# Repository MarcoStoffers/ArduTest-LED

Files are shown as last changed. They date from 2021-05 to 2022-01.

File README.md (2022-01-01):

# ArduTest-LED
ledtest_front

Based on an idea of https://jaycar.com.au

## Update: new Firmware V0.6 with adjustable LED PWM start voltage

The PWM start voltage for testing the LED was fixed set to 2.5V. This was good for standard LEDs. But if you want to test white or blue LEDs with 3V or higher, it won't work. So I added a setup for this startup voltage. Press "I up" ("Strom +") while switching on the tester and wait for the startup screen to complete.

lcdvstartsetup

Now you can adjust the LED voltage with the "V up" ("Spannung +") and "V down" ("Spannung -") keys. IF YOU SET THIS VOLTAGE TO HIGH, YOUR LED WILL BLOW UP! For storing this value, press "I down" ("Strom -") key.

If this is the first power up for new firmware version, the default value of 2.5V will be stored in EEprom. You will see a short notice on the LCD

eeprominitok

## An Arduino based LED Tester with LCD

Select the current and the destination voltage (your battery), connect the LED to the tester and get the needed value for a serial connected Resistor. You can also see the measured values for the LED (forward voltage and current).

To dimm the LED, you can lower the current during measurement down to 3mA or up to 40mA. The Tester always starts with a default current of 10mA!

## Tips for DIYing

The housing is designed in Fusion360. You can print it on any 3D FDM Printer with PLA or any other material you want. You will need 4x threaded inserts in M3 and 4 screws M3x25 to hold the front on the housing. The Frontplate is desgined in Inkscape in german. You can edit the SVG file for your own like.

The buttons are also designed in Fusion360. You will need an SLA Printer to get good results (FDM Printer will not work here fine).

## EasyEDA Source for PCB ordering through JLCPCB

https://oshwlab.com/mstoffers/ArduTest-LED

## License

CreativeCommonLicense

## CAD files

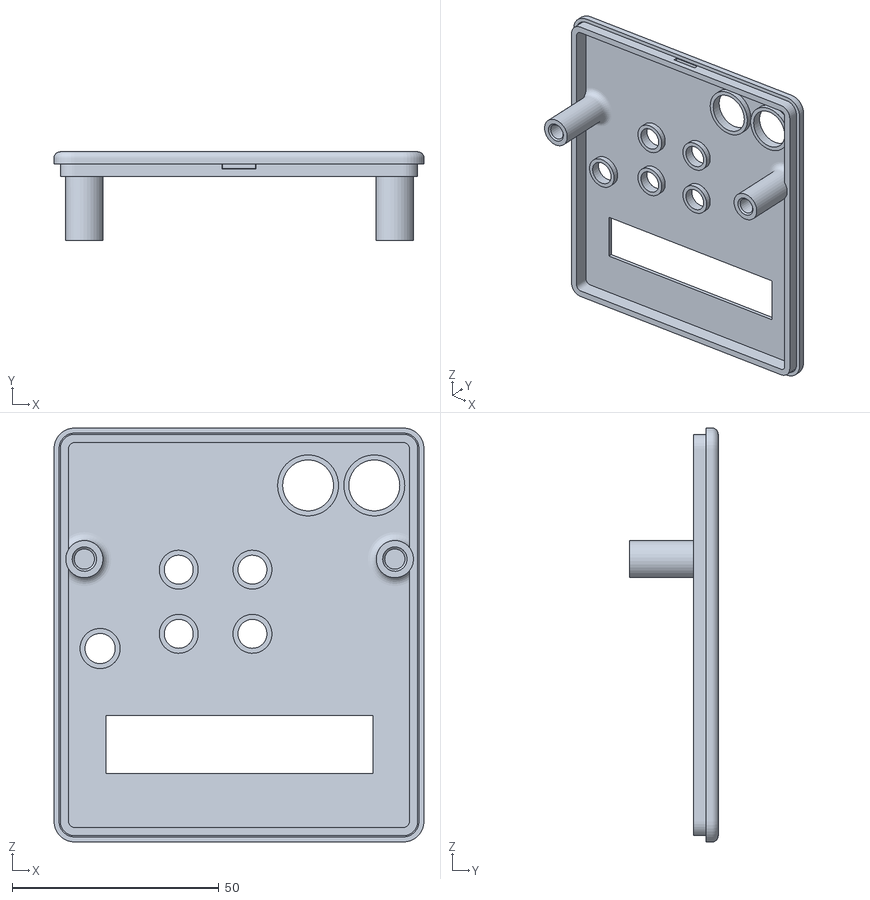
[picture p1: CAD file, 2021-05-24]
Housing/ArduTest LED Housing Top.stl
89.4 x 21.4 x 100.0

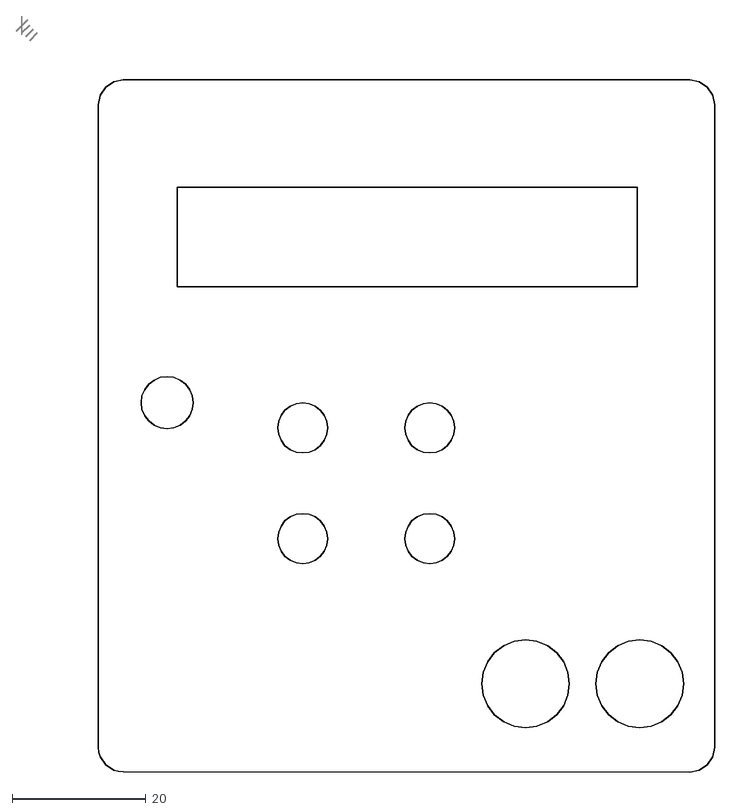
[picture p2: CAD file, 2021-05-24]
Housing/ArduTest LED Housing Front.dxf
104.4 x 113.0

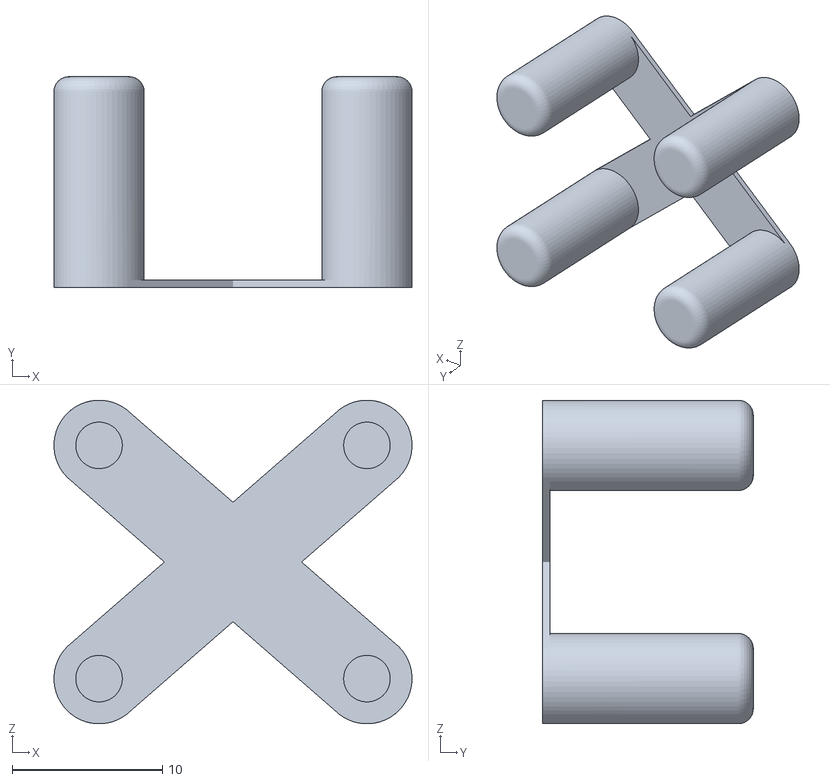
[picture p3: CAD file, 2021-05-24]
Housing/ArduTest LED Housing Button 4x.stl
23.8 x 14.0 x 21.5

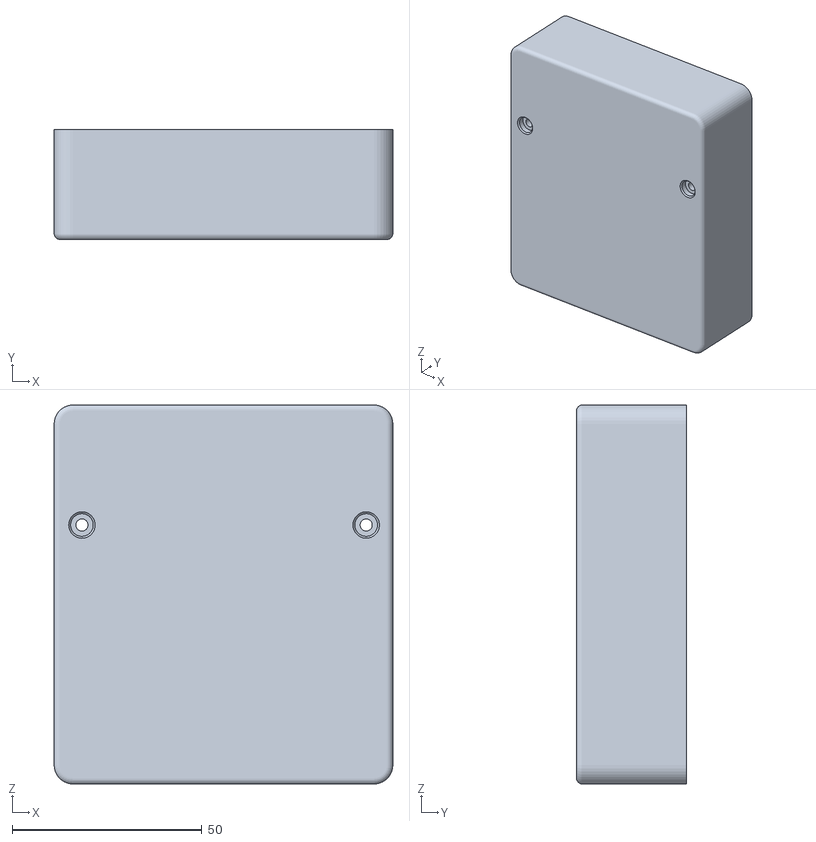
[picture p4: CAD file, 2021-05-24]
Housing/ArduTest LED Housing Bottom.stl
89.4 x 29.0 x 100.0

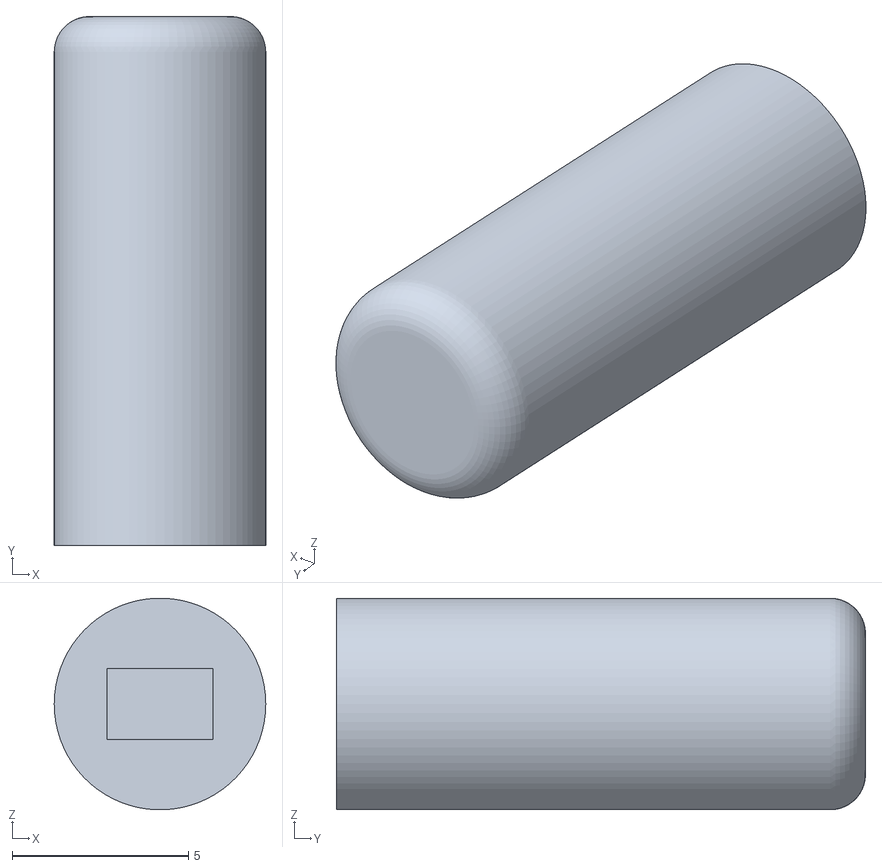
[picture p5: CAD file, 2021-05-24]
Housing/ArduTest LED Housing Button Power.stl
6.00 x 15.0 x 5.99

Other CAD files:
Housing/ArduTest LED Housing.f3z

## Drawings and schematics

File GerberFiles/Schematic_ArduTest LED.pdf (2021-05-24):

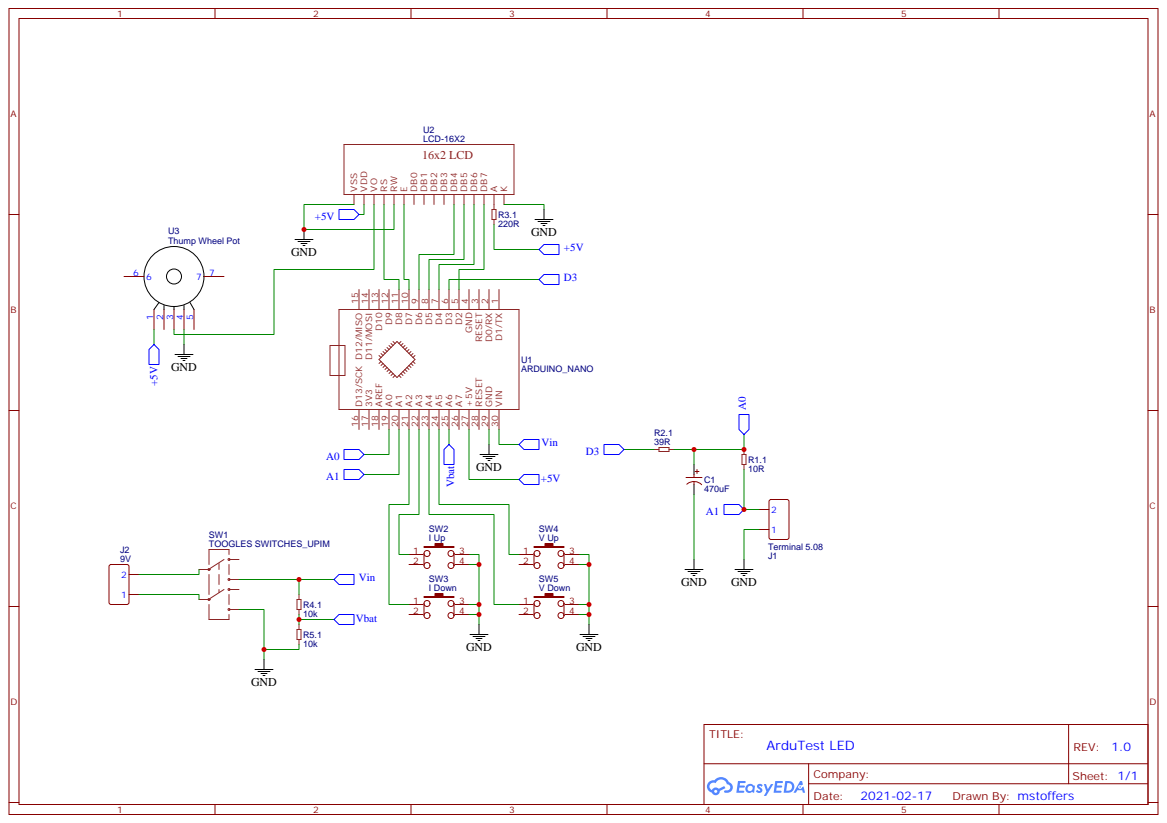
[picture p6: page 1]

1 VIN 30 GND 29 RESET 28 +5V 27 A7 26 A6 25 A5 24 A4 23 A3 22 A2 21 A1 20 A0 19 AREF 18 3V3 17 D13/SCK 16 D12/MISO 15

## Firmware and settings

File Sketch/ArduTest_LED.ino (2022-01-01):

/* -----------------------------------------------------------------------
**  ArduTest LED
** ==============
**
**  Original from https://jaycar.com.au
**
**  DPIN--39R--+--10R---TESTLED---GND
**         |      |         |
**        470u    ATOP     ABOT
**         |
**        GND
**
**  Measures LED characteristics by charging up the cap to deliver target 
**  current and find forward voltage. From target current, we can calculate 
**  R to be used with a design supply voltage.
**  
**  Revision History:
**  0.1: - take original code and port it no new Hardware
**  0.2: - optimize code and cleanup
**  0.3: - rewrite LCD display routine to minimize flicker
**  0.4: - rewrite PWM routine to avoid LED over current
**  0.5: - add voltage test routine while pressing I-Down at startup
**  0.6: - add setup for led forward voltage at measure-start (be careful what you are doing here!)
**
** Inputs:
** --------
** A0 = analog Voltage ATOP
** A1 = analog Voltage ABOT
** A2 = Key I Down
** A3 = Key I Up
** A4 = Key V Down
** A5 = Key V Up
** A6 = analog Voltage Battery
**
** Outputs:
** ---------
** D8 = LCD RS 
** D7 = LCD Enable
** D6 = LCD Data 4
** D5 = LCD Data 5
** D4 = LCD Data 6
** D2 = LCD Data 7
** D3 = PWM output
** 
** EEPROM data:
** -------------
** 0 - values stored? (255 = no / 0 = yes)
** 1 - LED voltage start PWM vlaue (8bit)
**
** Board:
** -------
** Arduino Nano V3 | Print: ArduTest LED V0.2
** 
** Author: M.Stoffers
** Year: 2022
** License: CC (BY|NC|SA)
** -------------------------------------------------------------------------*/  
#include <LiquidCrystal.h>
#include <avr/eeprom.h>

// -----------------------------
// PIN-defines
// -----------------------------
#define Version "V0.6"
#define LCD_D2 2
#define LCD_D4 4
#define LCD_D5 5
#define LCD_D6 6
#define LCD_D7 7
#define LCD_D8 8
#define DPIN 3
#define ATOP A0
#define ABOT A1
#define ABAT A6
#define KEY_I_UP A3
#define KEY_I_DW A2
#define KEY_V_UP A5
#define KEY_V_DW A4

// -----------------------------
// System-defines
// -----------------------------
#define OSAMP 16                                                  // Number of oversamples
#define LCDINT 250                                                // LCD update interval
#define KEYINT 150                                                // Key check interval
#define VCCINT 5000                                               // VCC read interval

#define between(x, a, b)  (((a) <= (x)) && ((x) <= (b)))

// -----------------------------
// declares
// -----------------------------
LiquidCrystal lcd(LCD_D8, LCD_D7, LCD_D6, LCD_D5, LCD_D4, LCD_D2);

// -----------------------------
// variables
// -----------------------------
uint8_t pins[]={KEY_I_UP, KEY_I_DW, KEY_V_UP, KEY_V_DW};          // array of Key pins

uint8_t ma_Char[] = { 0x0A, 0x15, 0x15, 0x00, 0x0E, 0x11, 0x1F, 0x11 };
uint8_t set1_Char[] = { 0x09, 0x15, 0x11, 0x09, 0x05, 0x15, 0x09, 0x00 };
uint8_t set2_Char[] = { 0x17, 0x02, 0x02, 0x12, 0x02, 0x02, 0x12, 0x00 };
uint8_t led1_Char[] = { 0x00, 0x0C, 0x0A, 0x09, 0x18, 0x09, 0x0A, 0x0C };
uint8_t led2_Char[] = { 0x03, 0x13, 0x14, 0x10, 0x1F, 0x10, 0x10, 0x10 };
uint8_t bat1_Char[] = { 0x00, 0x0C, 0x1E, 0x1E, 0x1E, 0x1E, 0x1E, 0x1E };
uint8_t bat2_Char[] = { 0x00, 0x0C, 0x1E, 0x12, 0x12, 0x1E, 0x1E, 0x1E };
uint8_t bat3_Char[] = { 0x00, 0x0C, 0x1E, 0x12, 0x12, 0x12, 0x12, 0x1E };

uint16_t VCC;                                                     // exact VCC
uint32_t vbat;                                                    // battery voltage
uint8_t pwmout=0;                                                 // pwm output of current driver
long atop, abot, arr, abat;                                       // analog sample values
long vled, vrr, irr, pset;                                        // LED voltage, Resistor voltage, resistor current, display power
uint8_t itest=10;                                                 // test current, starting at 10mA
uint32_t vset =12000;                                             // display voltage, start at 12V
uint8_t battery_status;                                           // battery status to display bat symbol

uint32_t r_calc, rval, r24[]={10,11,12,13,15,16,18,20,22,24,27,30,33,36,39,43,47,51,56,62,68,75,82,91};
uint16_t r24_mul;                                                 // variables to determine R24 value
uint8_t r24_loop;
boolean r24_found;
boolean rvalid=false;                                             // flag if resistor value is valid 

boolean lcdflash = false;                                         // lcd flashing phase variable
long lastlcd=0, lastkey=0, lastvcc=0;                             // time of last lcd & key update

uint16_t LED_forw_v_start;                                        // LED measure startup up voltage
uint16_t vsetup=0;
boolean while_loop = true;

// -----------------------------
// Setup
// -----------------------------
void setup() {
  pinMode(DPIN,OUTPUT);                                           // Set PWM pin aus Output
  for(uint8_t i=0; i<4; i++) pinMode(pins[i], INPUT_PULLUP);      // Define button Pins as Input with Pullup resistors

  readVcc();                                                      // Read VCC ...

  analogReference(DEFAULT);                                       // ... set ADC Reference back to default
  delay(2);                                                       // ... and wait for ADC to become stable
  
  lcd.begin(16, 2);                                               // LCD initialize 
  
  lcd.createChar(1, ma_Char);                                     // create special character#1 : mA
  lcd.createChar(2, set1_Char);                                   // create special character#2 : SE
  lcd.createChar(3, set2_Char);                                   // create special character#3 : T
  lcd.createChar(4, led1_Char);                                   // create special character#4 : LED symbol left
  lcd.createChar(5, led2_Char);                                   // create special character#5 : LED symbol right
  lcd.createChar(6, bat1_Char);                                   // create special character#6 : Battery symbol full
  lcd.createChar(7, bat2_Char);                                   // create special character#6 : Battery symbol half
  lcd.createChar(8, bat3_Char);                                   // create special character#6 : Battery symbol empty

  abat = analogoversample(ABAT,OSAMP);                            // read battery voltage and calc to mV
  vbat = (abat * VCC/1023)*2;

  if(between(vbat,8700,9900)) battery_status = 1;                 // decide to show which battery symbol
  else if(between(vbat,8000,8699)) battery_status = 2;            // 1=full, 2=half, 3=empty
  else battery_status = 3;                                        // if voltage to low, show empty battery symbol

  Check_EEPROM();                                                 // check if EEPROM is already initialized and read values
  
  StartupScreen();                                                // Show Startup Screen

  if(!digitalRead(KEY_I_DW)) Voltage_Test();                      // If key "current down" is pressed at startup, call Sub voltage test
  if(!digitalRead(KEY_I_UP)) Voltage_Setup();                     // If key "current up" is pressed at startup, call Sub voltage setup
  
  Draw_Init_LCD();
}

// -----------------------------
// Mainprogram
// -----------------------------
void loop() {
  rvalid=false;                                                   // set flag to not valid
  pset=0;                                                         // set power consumption var to zero
  
  atop = analogoversample(ATOP,OSAMP);                            // read voltage ATOP
  abot = analogoversample(ABOT,OSAMP);                            // and ABOT including oversample
  
  arr = atop - abot;                                              // this is the analog value across the 10R sense resistor
  if(arr < 0) arr = 0;                                            // sanity check
  
  vled = abot * VCC/1023;                                         // calc voltage across LED
  vrr = arr * VCC/1023;                                           // calc voltage across sense resistor
  irr = vrr / 10;                                                 // led and resistor current in mA

  if(irr < 1) pwmout = LED_forw_v_start;                          // if test LED is not present put PWM to given startup voltage 
  else {
    if(irr < itest) {                                             // ramp up current if too low
      pwmout++;
      if(pwmout > 255) pwmout = 255;
    }    
    if(irr > itest){                                              // ramp down if too high
      pwmout--;
      if(pwmout < 0) pwmout = 0;
    }
    if(irr > 34){                                                 // ramp down quick if too too high
      pwmout = pwmout - 5;
      if(pwmout < 0) pwmout = 0;
    }
    if(irr > itest * 3){                                          // ramp down quick if too too high
      pwmout = pwmout - 5;
      if(pwmout < 0) pwmout = 0;
    }
  }
  analogWrite(DPIN,pwmout);                                       // output new PWM

  if(irr < 1) rvalid = false;
  else if(vled > vset) rvalid = false;                            //if vled>vset, no valid resistor exists
  else {
    r_calc = (vset - vled) / itest;                               // calc needed resistor

    r24_mul = 1;                                                  // set all var for R24 search to start
    r24_loop = 0;
    r24_found = false;
  
    while(r24_loop < 4) {                                         // find next highest E24 value
      for(int i=0;i<24;i++){                                      
        if(!r24_found && ((r24[i] * r24_mul) > r_calc)){
          rval = r24[i]*r24_mul;
          rvalid=true;
          r24_found=true;
          r24_loop = 4;
       }
      }
      if(!rvalid) {                                               // if R24 search before has not matched
       r24_loop ++;                                                
       r24_mul *= 10;                                             // try next decade
      }
    }
  }
  if(abs(irr-itest)>(itest/5)+1){rvalid=false;}                   // has current settled within 20%?
  
  if(rvalid){pset=itest*itest*rval;}                              // this will be in microwatts (milliamps squared)
  
  if(millis()-lastlcd>LCDINT){                                    // check if display needs to be updated
    lastlcd=millis();
    dolcd();                                                      // update display
    lcdflash=!lcdflash;                                           // toggle flash variable
  }
  if(millis()-lastkey>KEYINT){                                    // do keys needs to be checked?
    lastkey=millis();
    dobuttons();
  }
  if(millis()-lastvcc>VCCINT){                                    // do VCC needs to be re-read?
    lastvcc=millis();
    readVcc();                                                    // Read VCC ...

    analogReference(DEFAULT);                                     // ... set ADC Reference back to default  
    delay(2);                                                     // ... and wait for ADC to become stable
  }
  delay(1);
} 

// -----------------------------
// Subroutine to update LCD
// -----------------------------
void dolcd(){
  lcd.setCursor(3,0);                                             // set postion first line|4th character
  if(itest>9) lcd.write(((itest/10)%10)+'0');                     // write tens of I-Test ...
  else lcd.write(' ');                                            // ... blank tens if zero
  lcd.write((itest%10)+'0');                                      // write ones of I-Test
  lcd.write(1);                                                   // write mA symbol and spacer
  lcd.write('|');
  
  if(vset>9999) lcd.write(((vset/10000)%10)+'0');                 // write tens of V-Set ..
  else lcd.write(' ');                                            // ... blank if zero
  lcd.write(((vset/1000)%10)+'0');                                // write ones of V-Set
  lcd.write('v');lcd.write(' ');                                  // and the electrical characteristic
  
  
  if((pset>249999)&&(lcdflash)){                                  // if power is above 1/4 watt
    lcd.setCursor(15,1);                                          // blink a 'P' on position 16 in line 2
    lcd.write('P');
  }
  else {
    lcd.setCursor(15,1);
    lcd.write(' ');
  } 
  
  lcd.setCursor(3,1);                                             // set postion second line|4th character
  
  if(irr < 1){                                                    // if test LED is not present ...
    lcd.print("-- ");                                             // print only dashes
  }
  else {                                                          // otherwise show the LED voltage
    lcd.write(((vled/1000)%10)+'0');
    lcd.write('.');
    lcd.write(((vled/100)%10)+'0');
  }
  lcd.write('v');lcd.print(" | ");                                // write 'V' char and spacer

  //actual LED current
  if(irr < 1) {                                                   // if test LED is not present ...
    lcd.print("- ");                                              // print only a dash
  }
  else {                                                          // otherwise show LED current
    if(irr>9) lcd.write(((irr/10)%10)+'0');
    else lcd.write(' ');
    lcd.write((irr%10)+'0');
  }
  lcd.write(1);                                                   // write 'ma' symbol
   
  if(rvalid){                                                     // if there is a calculated R24 value
    lcdprintrval(rval);                                           // call subroutine to print on LCD
    lcd.write(' ');
  }
  else {                                                          // otherwise leave field blank
    lcd.setCursor(11,0);
    lcd.print("     ");
  }
}

// -----------------------------
// Subroutine
// -----------------------------
void lcdprintrval(uint32_t rval){                                 // print a value in 10k0 format, always outputs 4 characters
  uint32_t mult=1;
  uint32_t modval;
  
  lcd.setCursor(11,0);                                            // go to position 12 in line one
  lcd.write(126);                                                 // and write the result-arrow
  
  if(rval>999) mult=1000;                                         // set multiplier
  if(rval>999999) mult=1000000;
  modval=(10*rval)/mult;                                          // convert to final format, save a decimal place
  if(modval>999){                                                 // print nnMn format
    lcd.write(((modval/1000)%10)+'0');
    lcd.write(((modval/100)%10)+'0');
    lcd.write(((modval/10)%10)+'0');
    lcdprintmult(mult);
  }
  else if(modval>99){                                             // print nnMn format
    lcd.write(((modval/100)%10)+'0');
    lcd.write(((modval/10)%10)+'0');
    lcdprintmult(mult);
    lcd.write(((modval)%10)+'0');
      }
  else{                                                           // print _nMn format
    lcd.write(' ');
    lcd.write(((modval/10)%10)+'0');
    lcdprintmult(mult);
    lcd.write(((modval)%10)+'0');
    }
  }

// -----------------------------
// Subroutine to print multiplier
// -----------------------------
void lcdprintmult(uint32_t mult){
  switch (mult){
    case 1: lcd.write(244); break;                                // print 'ohm' symbol
    case 1000:  lcd.print('k');break;                             // print 'kilo' ohm
    case 1000000: lcd.print('M');break;                           // print 'mega' ohm
  }
}

// -----------------------------
// Subroutine to read buttons
// -----------------------------
void dobuttons(){      
    if(!digitalRead(KEY_I_DW)) {                                  // if button I-Down is pressed
      itest=itest-1;                                              // lower test current by one
      if(itest<2) itest=2;                                        // and limit test current to 2mA
    }
    if(!digitalRead(KEY_I_UP)) {                                  // if button I-Up is pressed
      itest=itest+1;                                              // higher test current by one
      if(itest>30)itest=30;                                       // and limit test current to 30mA
    }
    if(!digitalRead(KEY_V_UP)) {                                  // if button V-Up is pressed
      vset=vset+1000;                                             // raise set voltage by 1000mV/1V
      if(vset>50000) vset=50000;                                  // and limit set voltage to 50V
    }
    if(!digitalRead(KEY_V_DW)) {                                  // if button V-Down is pressed
      vset=vset-1000;                                             // lower set voltage by 1000mV/1V
      if(vset<2000) vset=2000;                                    // and limit it to 2V
    }   
}

// -------------------------------
// Subroutine to Analog Oversample
// -------------------------------
long analogoversample(uint8_t pin,uint8_t samples){               
  long n=0;
  for(uint8_t i=0;i<samples;i++){                                 // read pin samples times ...
    n += analogRead(pin);                                         // ... add it to helper variable
  } 
  return n/samples;                                               // and return value dived by number of samples
}

// -------------------------------
// Subroutine to read VCC
// -------------------------------
void readVcc() { 
  ADMUX = _BV(REFS0) | _BV(MUX3) | _BV(MUX2) | _BV(MUX1);         // set analog reference to build in 1V15
  delay(2);                                                       // wait for Vref to settle
  ADCSRA |= _BV(ADSC);                                            // convert
  while (bit_is_set(ADCSRA,ADSC));                                // wait for conversion to become ready
  VCC = ADCL;
  VCC |= ADCH<<8;                                                 // read 16bit in total
  VCC = 1126400L / VCC;                                           // back-calculate AVcc in mV
}

// -------------------------------
// Subroutine to draw Start Screen
// -------------------------------
void StartupScreen() {
  lcd.setCursor(0,0);                                             // start in the upper left corner
  lcd.write(4);                                                   // draw the LED symbol
  lcd.write(5);
  lcd.setCursor(4,0);                                             // go to position 5 in line one
  lcd.print("ArduTest");                                          // write Text
  lcd.setCursor(14,0);                                            // go to position 15 in line one
  lcd.write(4);                                                   // and draw another LED symbol
  lcd.write(5);
  lcd.setCursor(1,1);                                             // go to position 2 in line two
  switch(battery_status) {                                        // show battery symbol according to input voltage
    case 1: lcd.write(6);                                         // battery symbol 'full'
    break;
    case 2: lcd.write(7);                                         // battery symbol 'half'
    break;
    case 3: lcd.write(8);                                         // battery symbol 'empty'
    break;
  }
  lcd.setCursor(6,1);                                             // go to position 7 in line two
  lcd.print("LED");                                               // print text
  lcd.setCursor(12,1);                                            // go to position 13 in line two
  lcd.print(Version);                                             // and print version number
  delay(5000);                                                    // wait for 5s
  lcd.clear();                                                    // and clear the LCD screen
}

// ---------------------------------
// Subroutine to draw Screen initial
// ---------------------------------
void Draw_Init_LCD() {
  lcd.setCursor(0,0);                                             // go to first position in line one
  lcd.write(2);                                                   // and draw 'SET' 
  lcd.write(3);
  lcd.setCursor(0,1);                                             // go to first posiiton in line two
  lcd.write(4);                                                   // and draw the LED symbol
  lcd.write(5);
}
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
